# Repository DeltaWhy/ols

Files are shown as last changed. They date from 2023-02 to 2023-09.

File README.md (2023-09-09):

# OLS
The Open Low-Profile Spherical keycap profile.
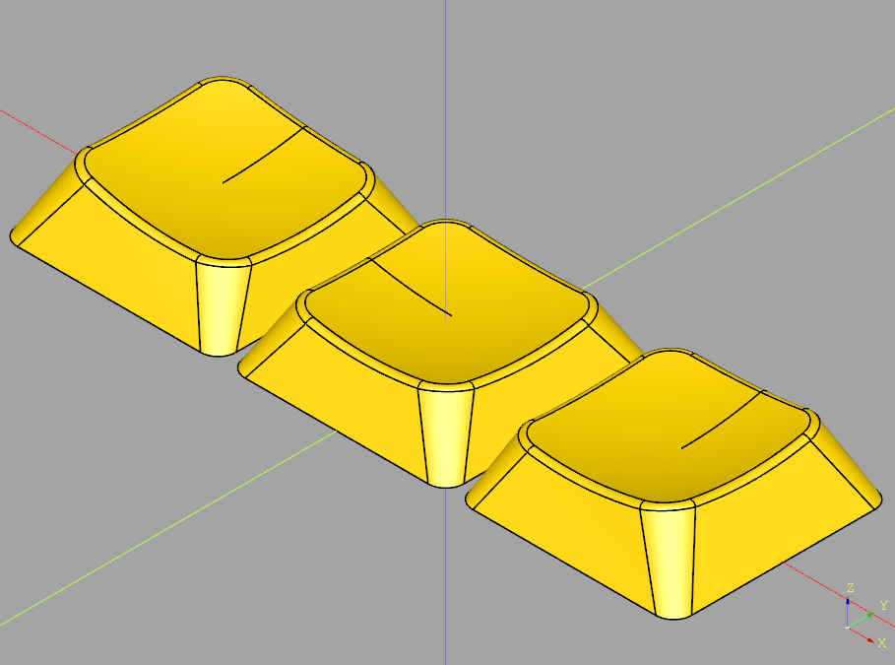
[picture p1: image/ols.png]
OLS isometric view

OLS side view
KLOR with OLS MX keycaps
Totem with OLS Choc Small keycaps

## Variations
Each folder contains STL and STEP files of each key. The ones with `-cut` are intended and pre-oriented for FDM printing, and the ones without are suitable for resin.

### MX
Keycaps with MX-compatible stems. Designed for low-profile switches (e.g. Gateron KS-27, Gateron KS-33, NuPhy, Kailh Choc v2) but should work with full-sized switches as well.

### Choc Large
Keycaps with Choc stems but MX spacing.

### Choc Small
Keycaps with Choc stems for Choc spacing. You'll have gaps if you use them on an MX-spaced board.

### Sprue
Sprued assemblies ready for printing at JLCPCB or other services. JLCPCB has a limit of 10 objects per file so these are built accordingly.

## Printing
For FDM printing, these caps work best oriented at 90 degrees to the build plate. This gives them a strong stem (particularly for Choc stems, any other orientation is very fragile) and a good finger surface even without sanding. You should probably use the `-cut` versions of the files which are pre-oriented. These cut off a bit of the rear edge to give a small flat surface for build plate adhesion.

My settings:
|Setting|Value|Note|
|---|-----|----|
|Layer height|0.12mm|Smaller layer heights don't improve the quality very much.|
|First layer height|0.2mm||
|Perimeters/Shells|3 or more||
|Infill|20%|Doesn't matter, since they are so thin almost the whole print will be perimeters.|
|Supports|On build plate only||
|Support Z gap|0.12mm||
|Support interface|100%||
|Seams|Aligned||
|Raft|Depends|I had good results with R3 and R4 keycaps using a raft, but the R2 caps kept failing. Printing the `-cut` version directly on the build plate worked better for those. Glue stick helps.|
|Avoid crossing perimeters|On||
|Z-hop|0.24mm|Only when printing a batch - for a single keycap you don't need it.|
|Z-hop starting at|1mm||

For resin, you'll most likely want to use an "ABS-like" resin to ensure the stems are strong.

## Developing
Install [Miniforge](https://github.com/conda-forge/miniforge/#download), Miniconda, or another implementation of `conda`. Cadquery is only available as a conda package and not through pip.

Create a conda environment with the required packages:

```sh
conda env create -f environment.yml
```

Use cq-editor to edit and view your changes interactively:

```sh
cq-editor
```

Or render STL and STEP files automatically:

```sh
python generate.py
```

## License

<br />This work is licensed under a <a rel="license" href="http://creativecommons.org/licenses/by-sa/4.0/">Creative Commons Attribution-ShareAlike 4.0 International License</a>.

## Acknowledgements

This work was inspired by [LDSA](https://lowprokb.ca/products/ldsa-low-profile-blank-keycaps) and [OPK](https://github.com/cubiq/OPK) but is not directly based on either. Special thanks to the folks from fingerpunch Discord, who got me into the low-profile rabbit hole in the first place, and have given lots of helpful feedback along the way.

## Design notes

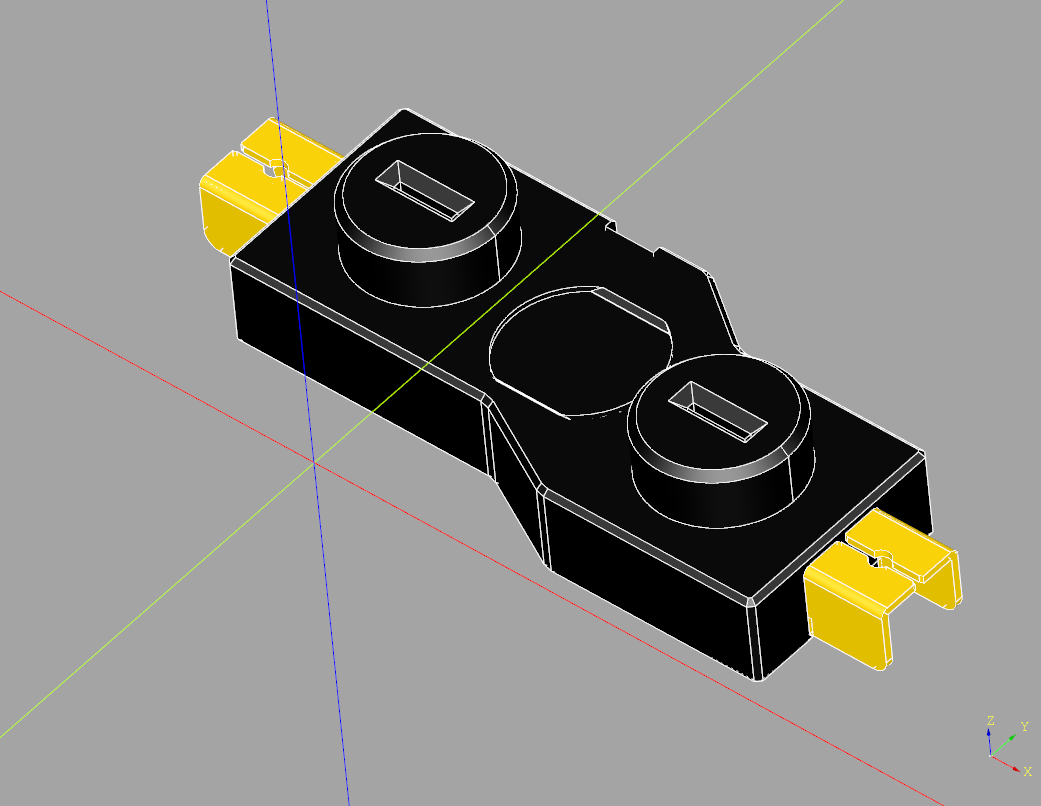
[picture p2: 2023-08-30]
other/ks33_socket.png

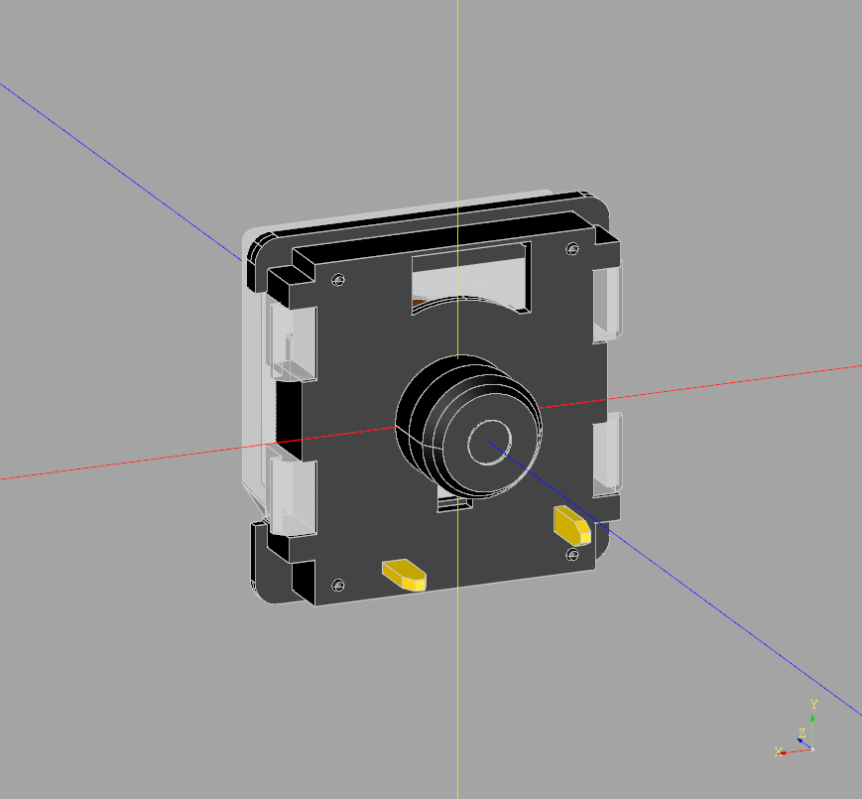
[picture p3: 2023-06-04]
other/ks33_2.png

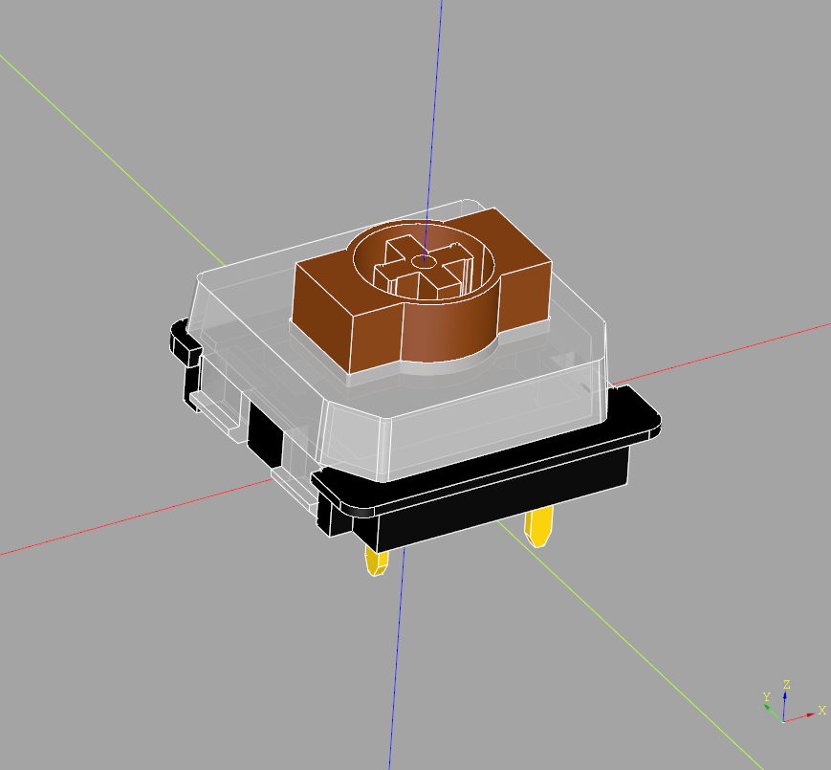
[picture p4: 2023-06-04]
other/ks33_1.png

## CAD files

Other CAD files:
generated/choc-lg/ols-v1-r3-cut.step
generated/choc-sm/ols-v1-r2-cut.step
generated/mx-extra/ols-v1-r2c-1.0u.step
generated/mx/ols-v1-r2-cut.step
generated/sprue/choc-lg-r4-x10.step
other/ks33.step
generated/choc-lg/ols-v1-r3-home-dot.step
generated/choc-sm/ols-v1-r4-cut.step
generated/mx-extra/ols-v1-r2-7.0u.step
generated/mx/ols-v1-thumb-1.5u-cut.step
generated/sprue/choc-sm-r2-x10.step
other/mx-to-choc.step
generated/choc-lg/ols-v1-r4-cut.step
generated/choc-sm/ols-v1-thumb-cut.step
generated/mx-extra/ols-v1-r2-3.0u-cut.step
generated/mx/ols-v1-r3-home-dot-cut.step
generated/sprue/choc-lg-mixed-x6.step
other/ks33_socket.step
generated/choc-lg/ols-v1-r2-cut.step
generated/choc-lg/ols-v1-r2-cut.stl
generated/choc-lg/ols-v1-r2.step
generated/choc-lg/ols-v1-r2.stl
generated/choc-lg/ols-v1-r3-cut.stl
generated/choc-lg/ols-v1-r3-home-cut.step
generated/choc-lg/ols-v1-r3-home-cut.stl
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

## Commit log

2023-02-25 Generate files
    [ols-v1-r2-cut.step, ols-v1-r2-cut.stl, ols-v1-r2.step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]
2023-02-25 rotate cut files
    [ols-v1-r2-cut.step, ols-v1-r2-cut.stl, ols-v1-r2.step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]
2023-03-01 choc large
    [mx-to-choc.step, mx-to-choc.stl, ols-v1-r2-cut.step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]
2023-05-10 adjust choc stem tolerance
    [ols-v1-r2-cut.step, ols-v1-r2-cut.stl, ols-v1-r2.step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]
2023-05-22 choc-sm first draft
    [ols-v1-r2-cut.step, ols-v1-r2-cut.stl, ols-v1-r2.step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]
2023-05-31 thumbs and choc sm revision
    [ols-v1-r2-cut.step, ols-v1-r2-cut.stl, ols-v1-r2.step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]
2023-05-31 MX extra and corne thumbs
    [ols-v1-r2-1.25u-cut.step, ols-v1-r2-1.25u-cut.stl, ols-v1-r2-1.25u.step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]
2023-06-04 unnecessary KS-33 switch model
    [ks33.step]
2023-06-04 WIP KS-33 socket
    [ks33_socket.step]
2023-08-30 wip: fix symmetry
    [ols-v1-r2.step, ols-v1-r3-home-dot.step, ols-v1-r3-home.step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]
2023-09-08 Regenerate after update
    [choc-lg-mixed-x6.step, choc-lg-r2-x10.step, choc-lg-r3-x8-dot-x2.step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]
